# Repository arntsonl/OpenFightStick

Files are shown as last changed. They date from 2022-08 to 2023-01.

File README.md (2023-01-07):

# Open Fight Stick 3D

The Open Fight Stick 3D (OFS3D) is a 3D printable modular arcade stick designed to be customizable and easy to print. The 3D models print build plate with a build plate of at least 240mm x 200mm. Each component of the OFS3D fits together using a similar concept to a tower joint and do not require traditional metal screws or fasteners. Magnets and concrete can be additionally added to the build to add strength to the joints and weight to the overall design.

## Features

* Choose your own button layout for the top panel (Vewlix or Stickless)
* Slide-in connections for easy assembly
* Brook board holes on bottom panel for PCB mounting
* Easy to modify Fusion360 models (non-commercial license)
* Ready to print STL files w/ assembly instructions
* Swappable side-panels (Small, Standard, Extra Large)
* Open Source and Free!

## Builds

### Version 1.0 - Project Boom Box
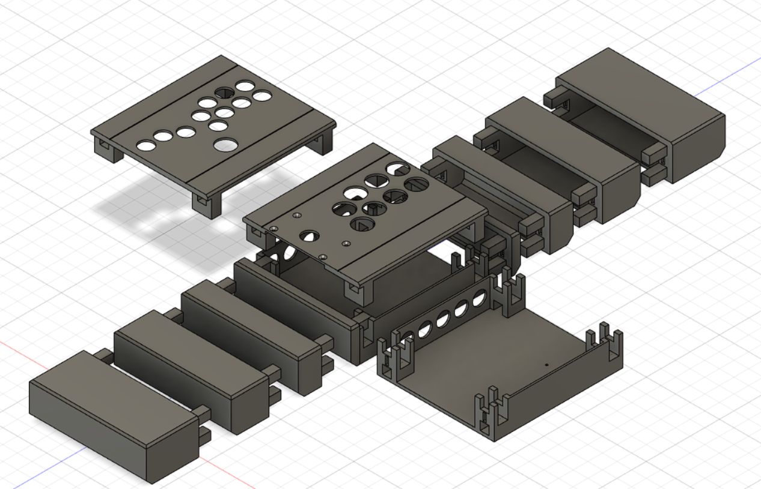
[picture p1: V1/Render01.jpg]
Open Fight Stick V1 3D Render Render of OFS3D v1


* Created in Fusion 360 (Non-Commercial License)
* Easy to print pieces
* Tower joints to hold top, bottom, and side panels together
* 5.5mm rectangular magnets to hold panels in place

* [Build Instructions](building.md)

## Acknowledgements

* [Luke Arntson](https://github.com/arntsonl/OpenFightStick) creator of the OFS3D
* The [OpenStick GP2040-CE Discord channel](https://discord.gg/KyQCHcjwJ2) for inspiration and feedback

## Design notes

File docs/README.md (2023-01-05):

# Open Fight Stick 3D

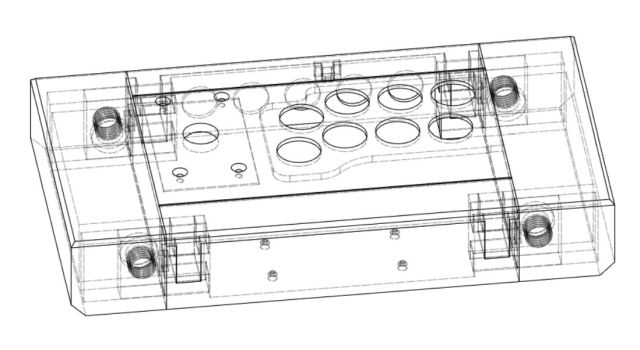
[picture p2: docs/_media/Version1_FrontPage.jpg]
Front-Page :size=600


* [Assembly Instructions](building.md)
* [Downloads](downloads.md)

The Open Fight Stick 3D (OFS3D) is a 3D printable modular arcade stick designed to be customizable and easy to print. The 3D models print build plate with a build plate of at least 240mm x 200mm. Each component of the OFS3D fits together using a similar concept to a tower joint and do not require traditional metal screws or fasteners. Magnets and concrete can be additionally added to the build to add strength to the joints and weight to the overall design.

## Features

* Make your own button layout for the top panel (Vewlix, Noir, Stickless, DIY!)
* Slide-in connections for easy assembly
* Tower joints for added strength and frame rigidity
* Brook board holes on bottom panel for PCB mounting
* Easy to modify Fusion360 models (non-commercial license)
* Ready to print STL files w/ assembly instructions
* Swappable side-panels (Small, Standard, Extra Large)
* Open Source and Free!

## Credits

* [Luke Arntson](https://github.com/arntsonl/OpenFightStick) creator of the OFS3D
* [OpenStickCommunity Discord](https://discord.gg/k2pxhke7q8) for inspiration and feedback
* [GP2040-CE](https://github.com/OpenStickCommunity/GP2040-CE) for endless hours of development fun
* [Level One Bar + Arcade](http://www.level1bar.com/) for all the support and good games

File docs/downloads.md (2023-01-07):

# Downloads

* [Printables.com Download](https://www.printables.com/model/362200-ofs3d-3d-printable-arcade-stick-v1-boombox)
* [Github.com](https://github.com/arntsonl/OpenFightStick/)

## Fusion 360 Source

* This Fusion-360 project is a non-commercial project. I hold no responsibilities of any party who modifies or distributes these plans.

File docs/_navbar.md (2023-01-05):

* [Home](/)
* [Assembly](assembly)
* [Downloads](downloads)
* [Builds](builds)

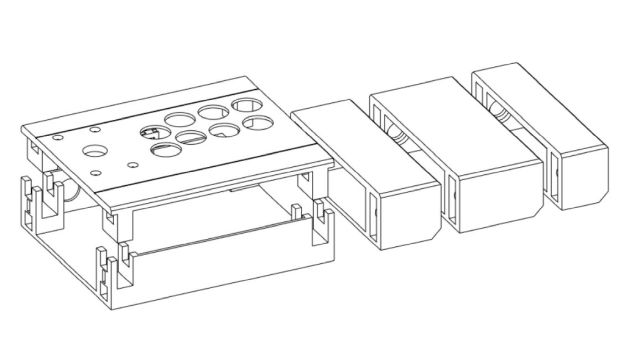
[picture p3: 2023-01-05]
docs/_media/Version1_Sides.jpg

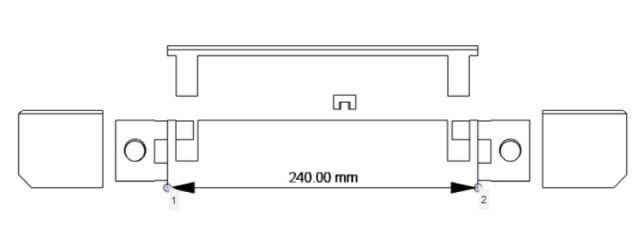
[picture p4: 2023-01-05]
docs/_media/Version1_Front-Explode.jpg

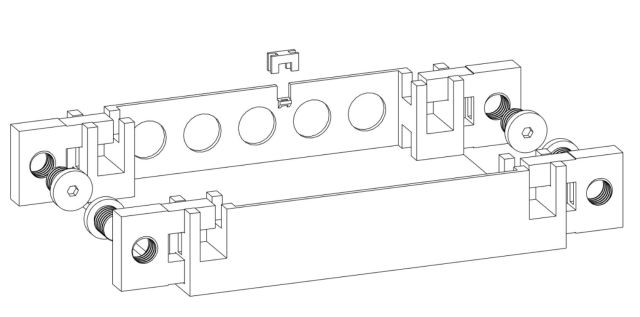
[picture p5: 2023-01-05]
docs/_media/Version1_Magnets.jpg

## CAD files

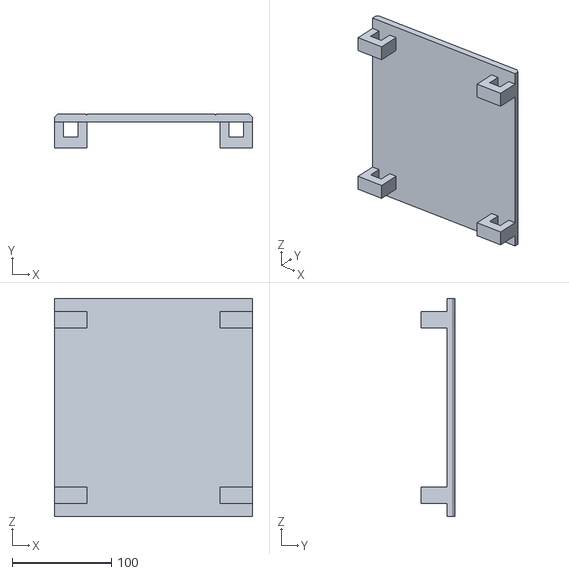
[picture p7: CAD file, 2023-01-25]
boombox/Top Blank (220mm).stl
200.0 x 34.0 x 220.0

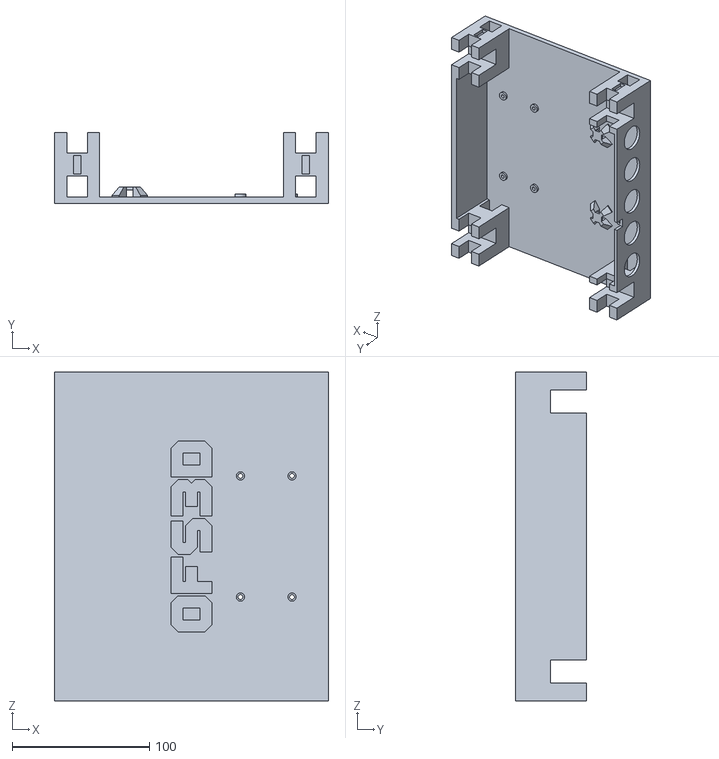
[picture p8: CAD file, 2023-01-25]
boombox/Bottom Plate (240mm).stl
200.0 x 52.0 x 240.0

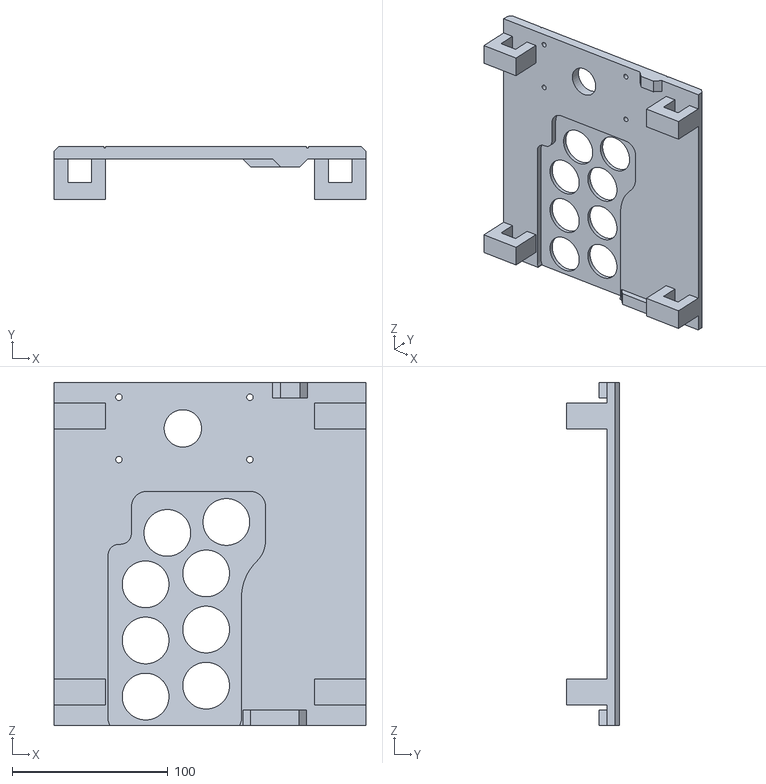
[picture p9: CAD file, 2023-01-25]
boombox/Top VLX (220mm).stl
200.0 x 34.0 x 220.0

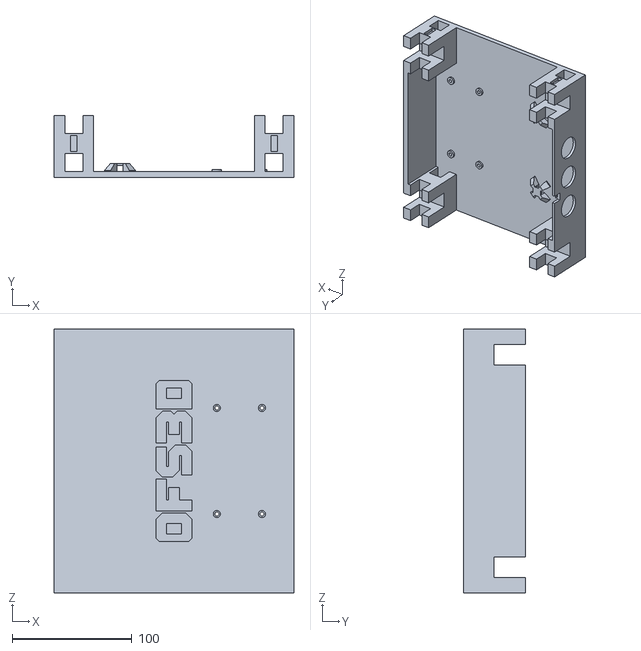
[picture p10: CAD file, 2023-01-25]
boombox/Bottom Plate (220mm).stl
200.0 x 52.0 x 220.0

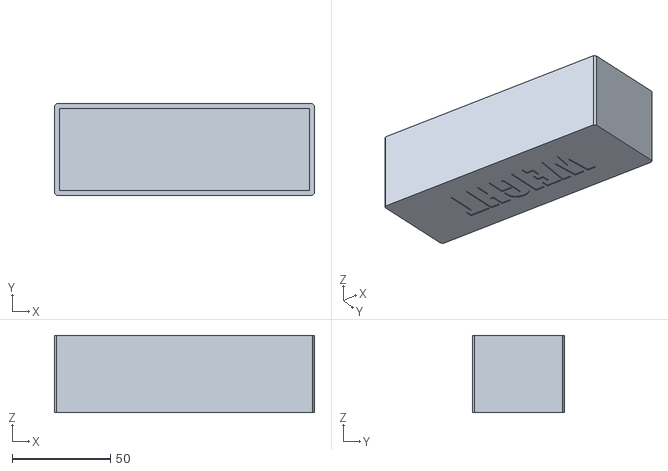
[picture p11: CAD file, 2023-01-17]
boombox/Side Panel Weight - Small.stl
132.0 x 46.5 x 39.3

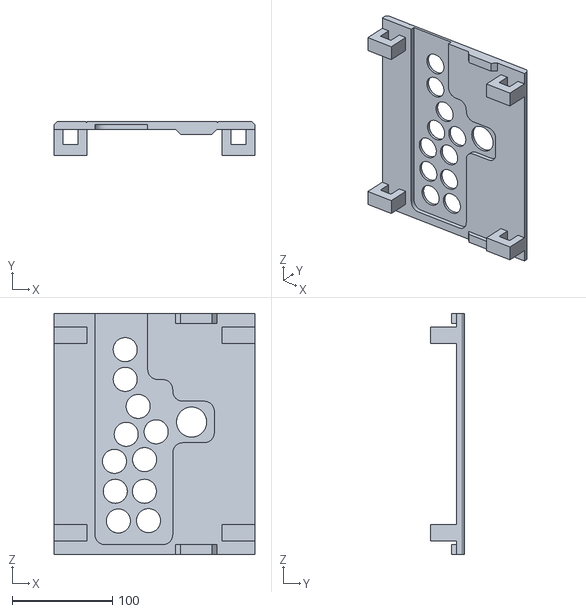
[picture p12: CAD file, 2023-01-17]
boombox/Top Stickless (240mm).stl
200.0 x 34.0 x 240.0

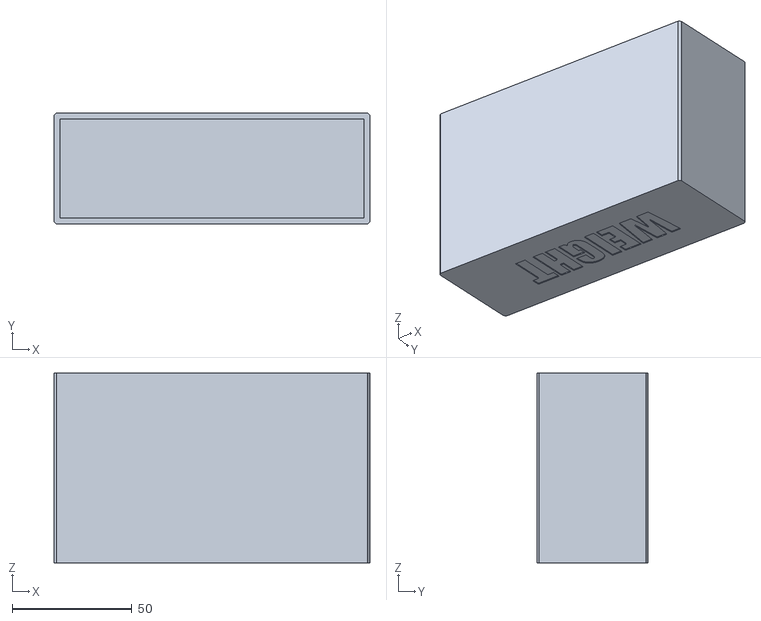
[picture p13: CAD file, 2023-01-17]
boombox/Side Panel Weight - X-Large.stl
132.0 x 46.5 x 79.3

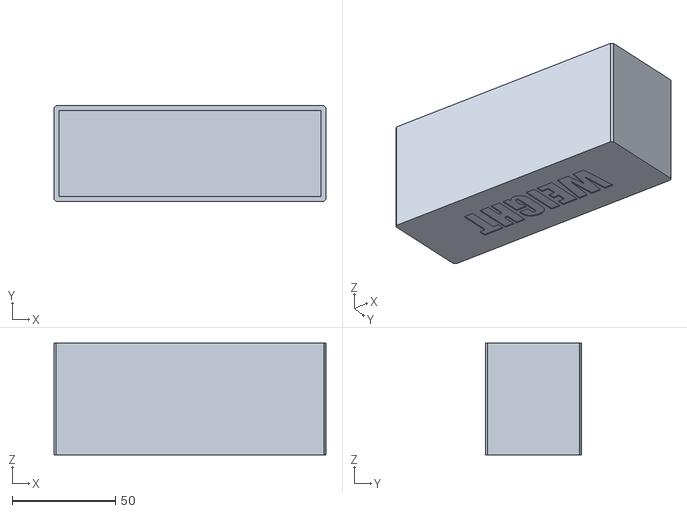
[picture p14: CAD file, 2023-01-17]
boombox/Side Panel Weight - Standard.stl
132.0 x 46.5 x 54.3

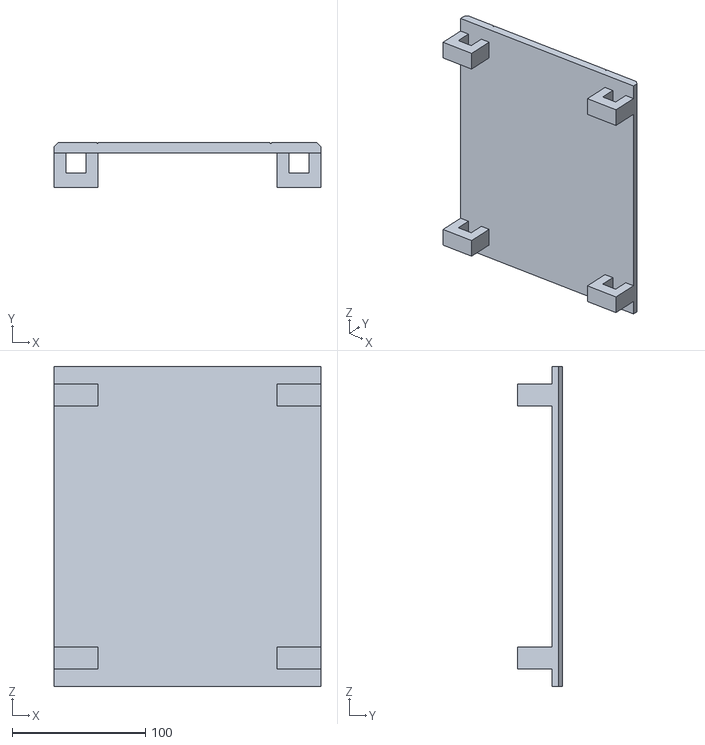
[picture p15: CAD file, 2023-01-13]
boombox/Top Blank.stl
200.0 x 34.0 x 240.0

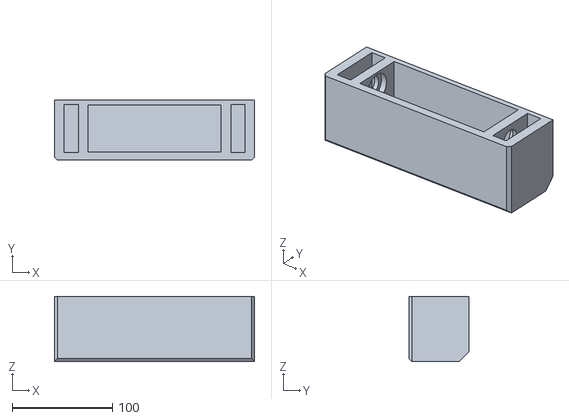
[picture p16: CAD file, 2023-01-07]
boombox/Side Panel - Standard.stl
200.0 x 60.0 x 65.0

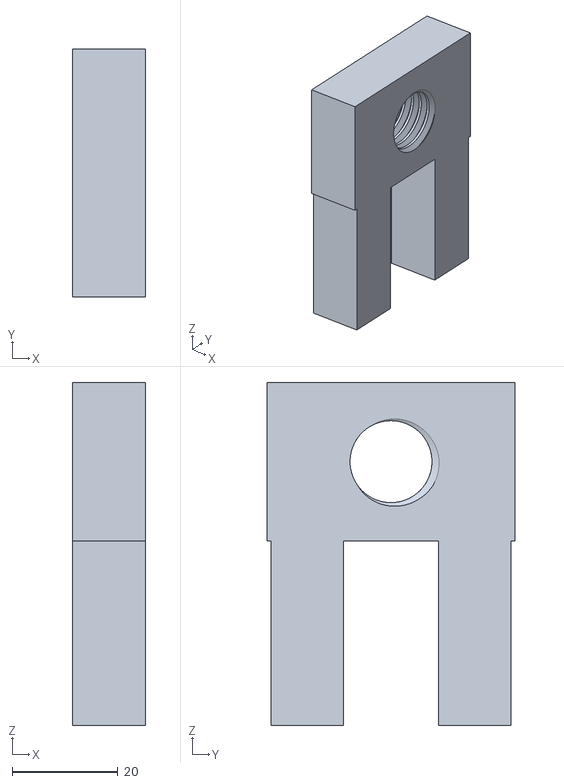
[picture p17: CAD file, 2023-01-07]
boombox/Side Panel Attachment.stl
13.8 x 47.0 x 65.0

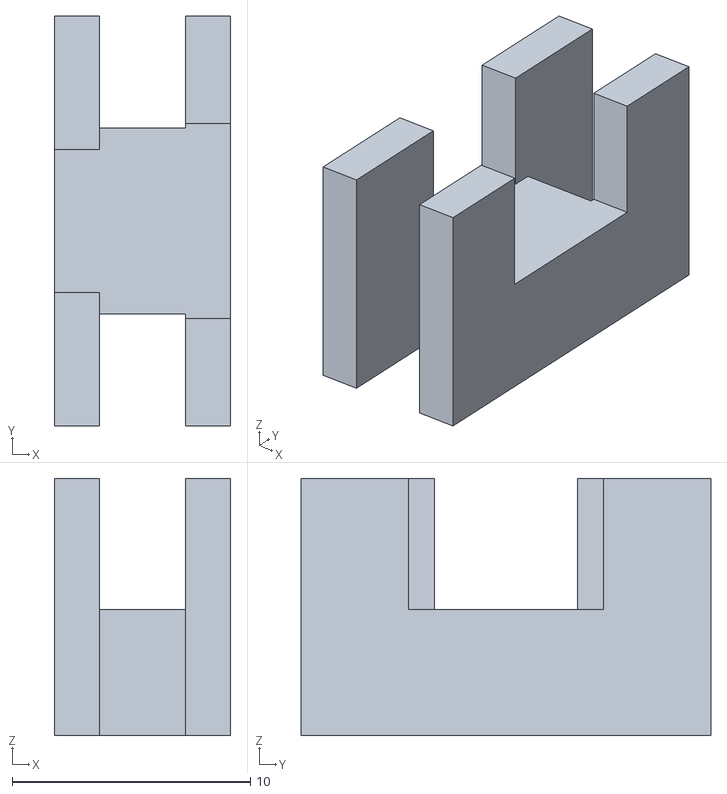
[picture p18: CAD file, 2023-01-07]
boombox/Flexible USB Tension.stl
7.40 x 17.2 x 10.8

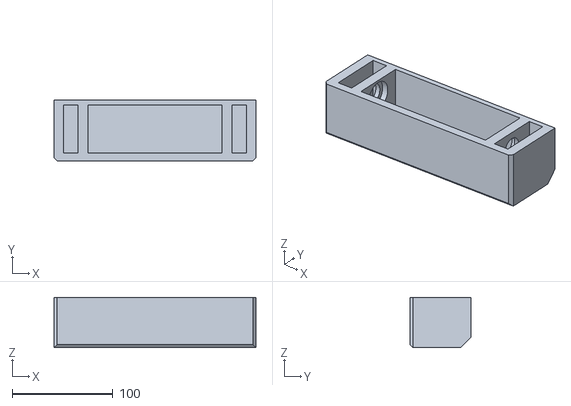
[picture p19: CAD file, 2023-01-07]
boombox/Side Panel - Small.stl
200.0 x 60.0 x 50.0

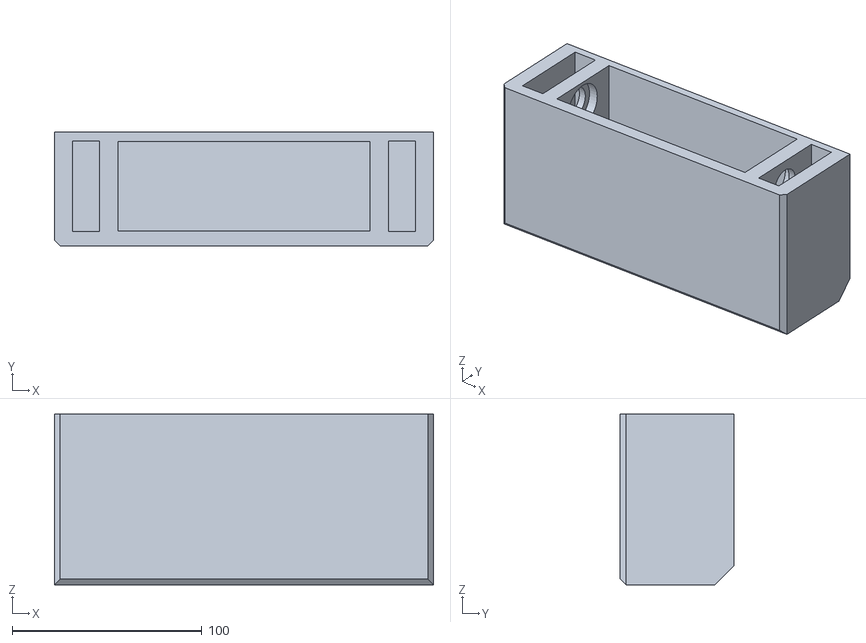
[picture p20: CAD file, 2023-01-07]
boombox/Side Panel - X-Large.stl
200.0 x 60.0 x 90.0

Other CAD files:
boombox/Top Stickless (220mm).stl
boombox/Top VLX (240mm).stl
boombox/Side Panel Screw.stl
boombox/OpenFightStick-BoomBox.f3d

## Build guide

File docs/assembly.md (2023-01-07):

# Version 1.0 : The Boom Box

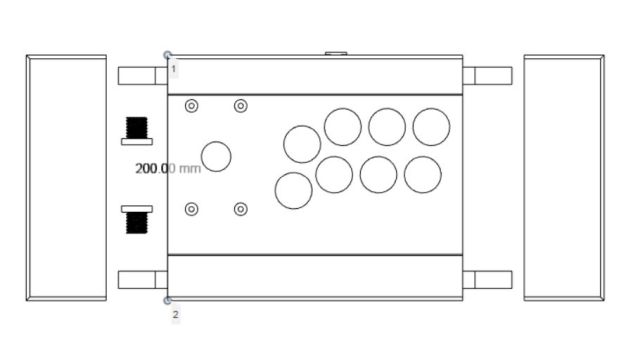
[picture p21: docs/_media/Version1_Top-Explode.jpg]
Verison 1.0 :size=600


## 3D Printer Requirements

### Must-have

* 200x240mm Print Bed Space
* 0.4mm nozzle

To print the OFS3D Boom Box, you will need a 3D printer capable of printing at least a 200mm x 240mm rectangle. It is recommended to use a 0.6mm nozzle, but a 0.4mm nozzle with PLA is plenty for the case.

### Nice-to-have

* Flexible filament capable such as nylon
* 0.6mm nozzle

You will also need to make sure your printer can handle bridges and your build plate is equipped to properly secure large printed pieces. Some glass plates can be cracked or broken by large, heavy prints.

## Components

To create an OFS3D Boom Box, you will need the following components:

* PLA, PETG, or ABS for Case
* For Stickless Build
  * 30mm Button x1
  * 24mm Buttons x16
* For Stick Build (VLX, Noir, Sega 2p)
  * Joystick
  * 30mm Button x8
  * 24mm Button x5
* Arcade Encoder Board with Brook holes
  * [TheTrain Breakout Boards](https://github.com/TheTrainGoes/GP2040-Projects)
  * [Brook Zero-Pi](https://www.brookaccessory.com/pro.php?m=d&pid=53169470)
  * [Brook UFB](https://www.brookaccessory.com/detail/06960737/)
* F13x5x3mm Rectangular Magnets x8 [Amazon Link](https://www.amazon.com/Magnetize-F13x5x3mm-Neodymium-Rectangle-MIM13-1905/)
* Super Glue for Magnets
* Optional
  * Flexible filament for cable relief
  * Small Zip Tie for cable Relief
  * Concrete or Cement Mix for weights

## Slicer Settings

The following PrusaSlicer settings work well for all of the components printed:

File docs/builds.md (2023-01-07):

# Builds

* [The Decepticon](builds?id=the-decepticon)
* [Mardi-Gras](builds?id=mardi-gras)
* Send me an [email](mailto:arntsonl@gmail.com) to showcase your build!

## The Decepticon
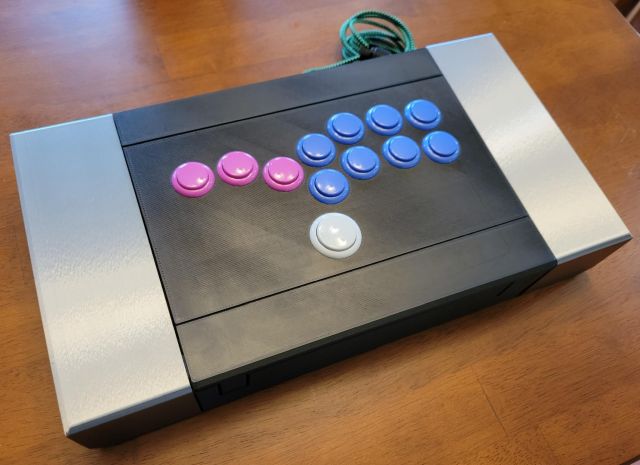
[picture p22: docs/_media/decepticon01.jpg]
Decepticon 01 :size=600

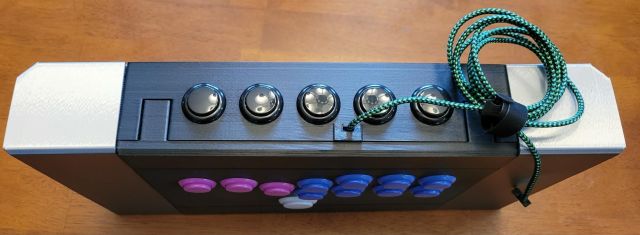
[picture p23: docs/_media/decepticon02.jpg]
Decepticon 02 :size=600

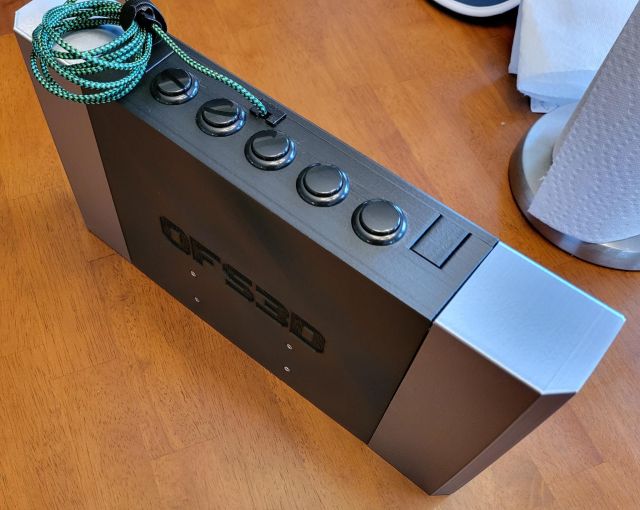
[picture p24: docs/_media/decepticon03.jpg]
Decepticon 03 :size=600


## Mardi-Gras
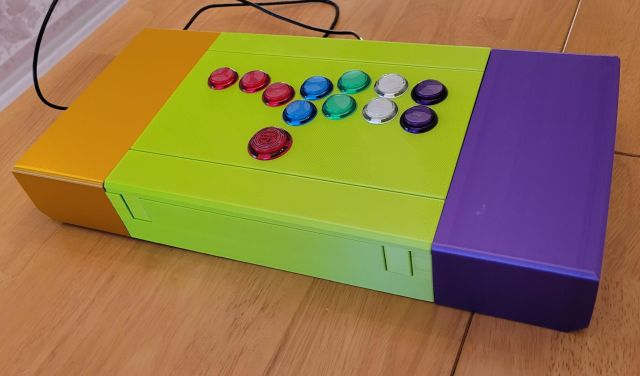
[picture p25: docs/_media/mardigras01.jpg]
MardiGras 01 :size=600

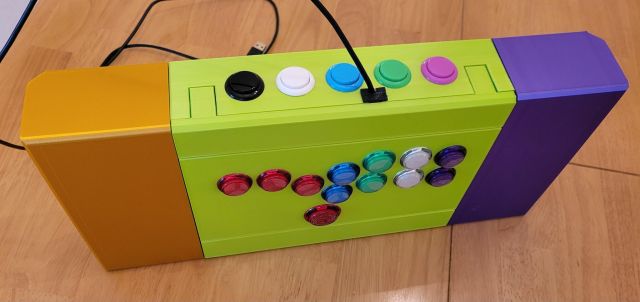
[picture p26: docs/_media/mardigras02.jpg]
MardiGras 02 :size=600

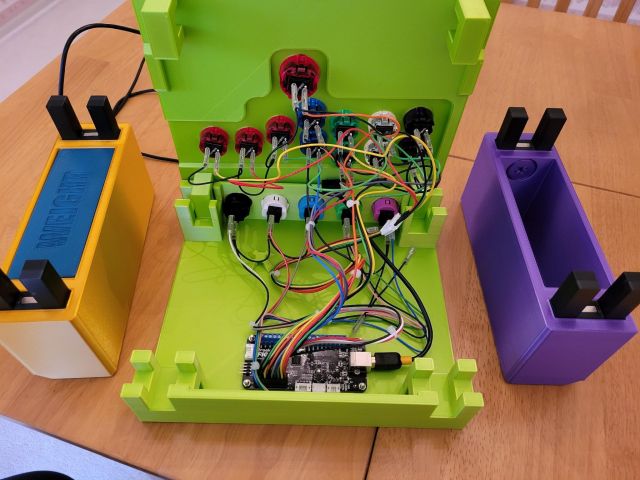
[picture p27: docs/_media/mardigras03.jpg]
MardiGras 03 :size=600


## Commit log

2022-08-25 Adding Fusion360 file, STL files, and print/renders. More to come as prints finish.
    [Bottom (220mm) (Brooks Holes).stl, Bottom (220mm).stl, OpenFightStick-V1.f3d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]
2022-08-26 Fixed magnet position, decreased size of posts to lower tolerances, added button box, added stubby (250mm) side panels
    [Bottom (220mm) (Brooks Holes).stl, Bottom (220mm).stl, OpenFightStick-V1.f3d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]
2023-01-07 Hosted files will be on Thingiverse for Boombox
    [Bottom (220mm) (Brooks Holes).stl, Bottom (220mm).stl, OpenFightStick-V1.f3d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]
2023-01-07 Added BoomBox to Github
    [Bottom Plate.stl, Flexible USB Tension.stl, OpenFightStick-BoomBox v1.f3d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]
2023-01-13 Fixed spacing on tops
    [OpenFightStick-BoomBox v1.f3d, OpenFightStick-BoomBox.f3d, Top Blank.stl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]
2023-01-17 Updated weights slightly for a tighter fit. I was finding the looser fit made them wobble once you added concrete.
    [OpenFightStick-BoomBox.f3d, Side Panel Weight - Small.stl, Side Panel Weight - Standard.stl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]
2023-01-25 Updated to add 220mm and some slight modifications to Bottom Plate.
    [Bottom Plate (220mm).stl, Bottom Plate (240mm).stl, Bottom Plate.stl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]
